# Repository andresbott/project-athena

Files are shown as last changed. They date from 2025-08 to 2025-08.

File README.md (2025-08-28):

# Project Athena
DIY PC Case Modding for Datahoarders 

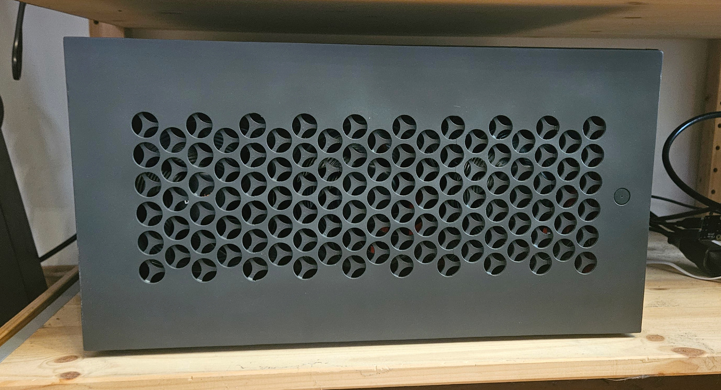
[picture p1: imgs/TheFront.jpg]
TheFront


## Background

When I was looking to replace my Home NAS, I desperately searched for an affordable, usable, and good-looking PC case with enough capacity for all my disks. Unfortunately, nowadays it is even hard to get a PC case that does not have a glass panel, and even harder to find one without a PSU shroud.

In the end, I settled on buying a *be quiet! Pure Base 500* and making the needed modifications myself: meet Project Athena.

## Features

With the modifications, you can set up a PC with **7×2.5" + 9×3.5" disks** or up to **25×2.5" disks** (depending on configuration) while keeping a regular ATX motherboard and PSU.

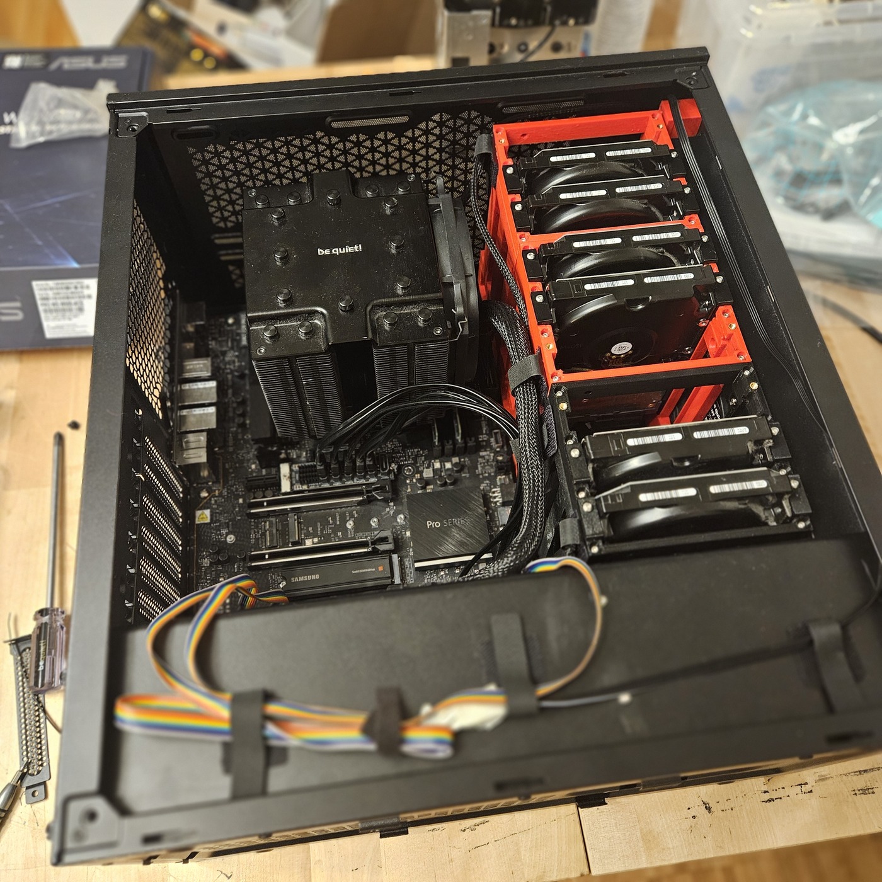
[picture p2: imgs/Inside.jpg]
Inside


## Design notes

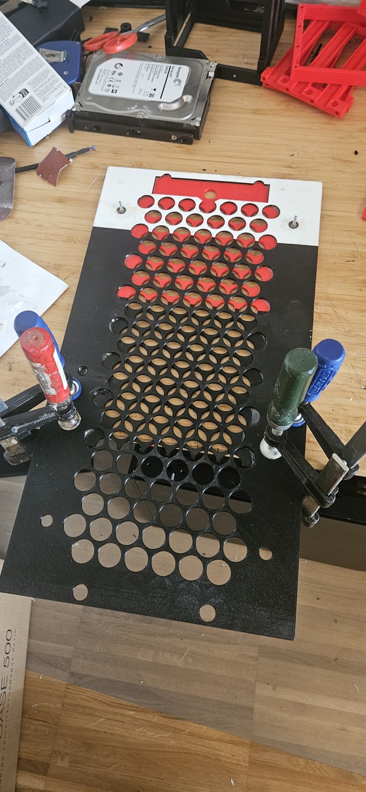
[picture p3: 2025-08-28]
imgs/TheFornt_01_Glue.jpg

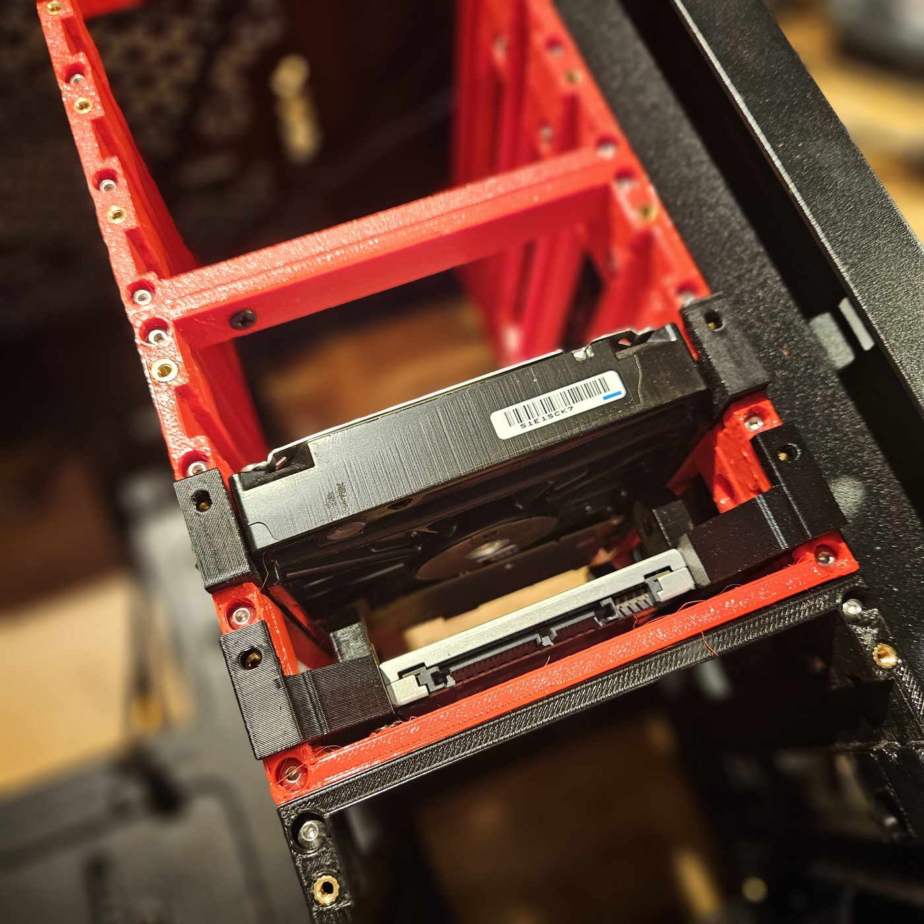
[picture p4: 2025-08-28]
imgs/DiskDetail.jpg

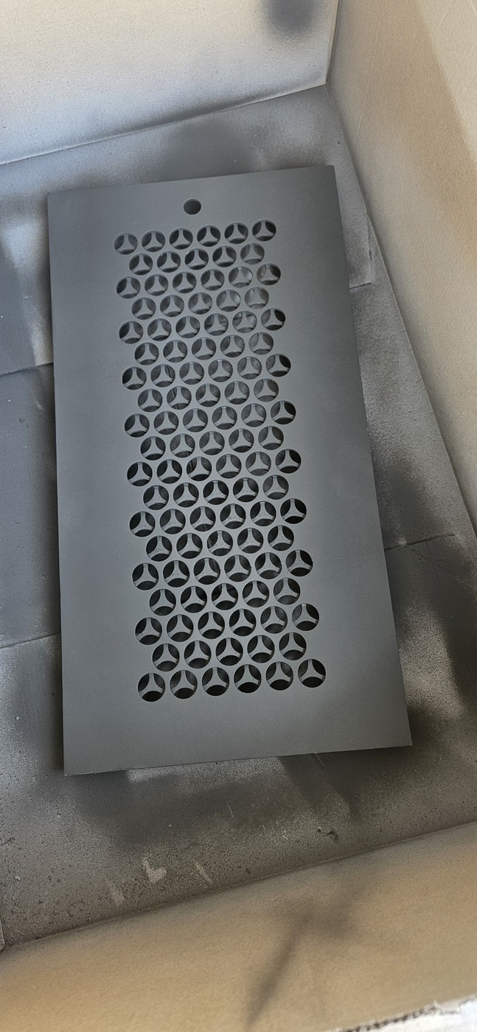
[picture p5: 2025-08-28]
imgs/TheFront_03_Paint.jpg

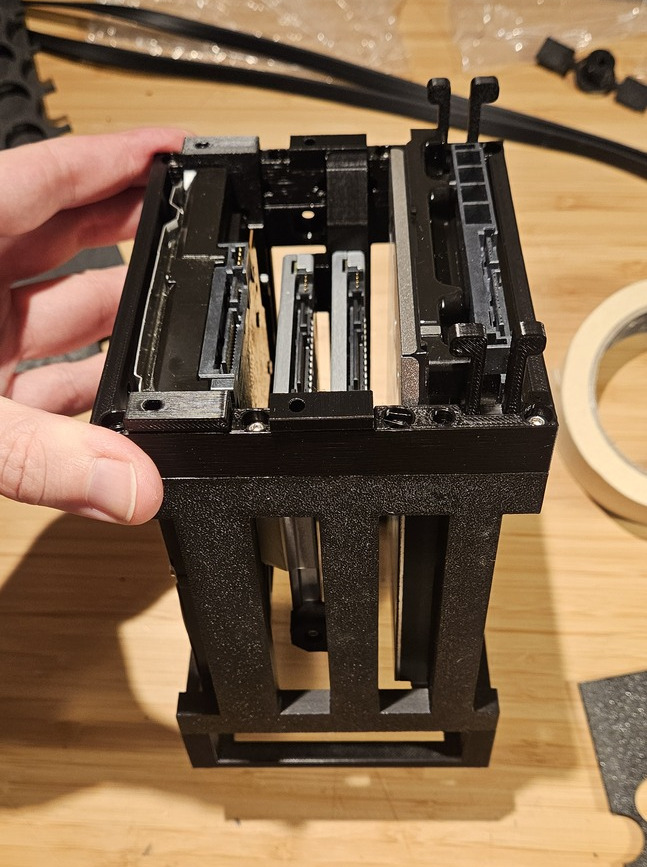
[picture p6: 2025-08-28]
imgs/HDD_Prototype_01.jpg

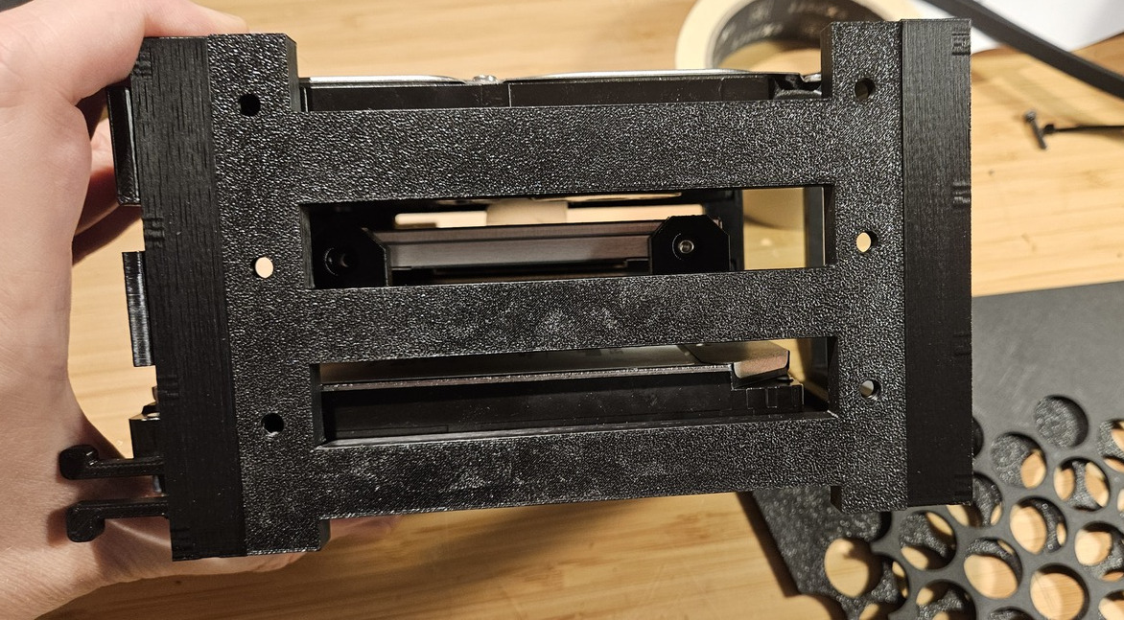
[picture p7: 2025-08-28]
imgs/HDD_Prototype_02.jpg

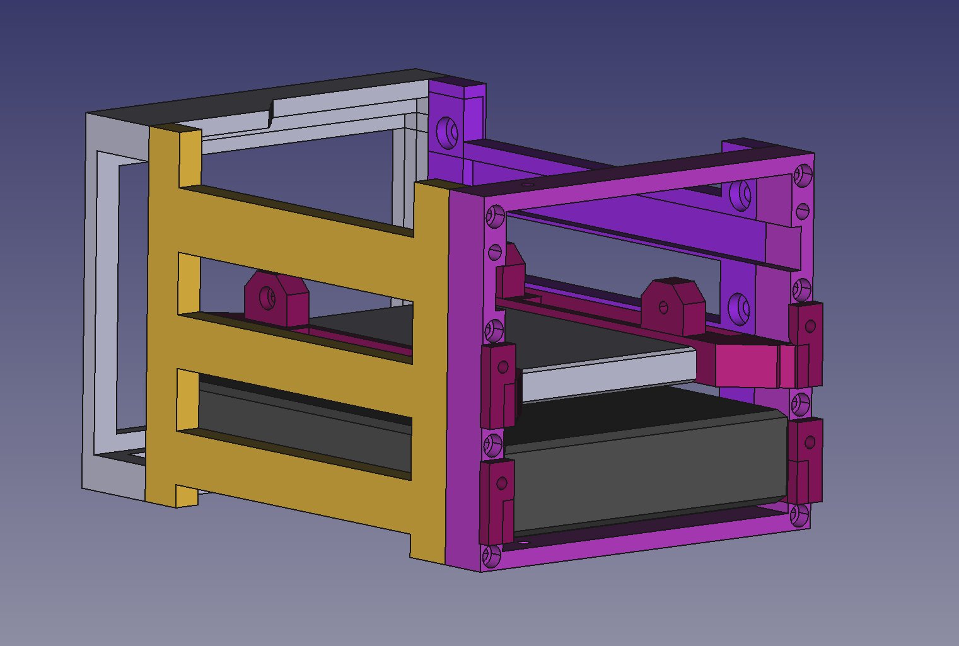
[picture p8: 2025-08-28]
HDDEnclosure/HDDEnclosure.jpg

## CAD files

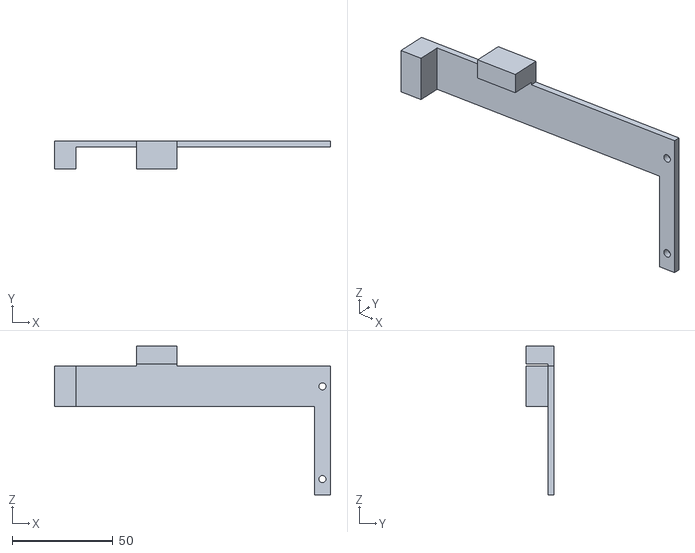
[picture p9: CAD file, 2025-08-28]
bottomSSD/files/SSDEnclosureBottom-HoleTemplate.obj
137.0 x 14.0 x 73.9

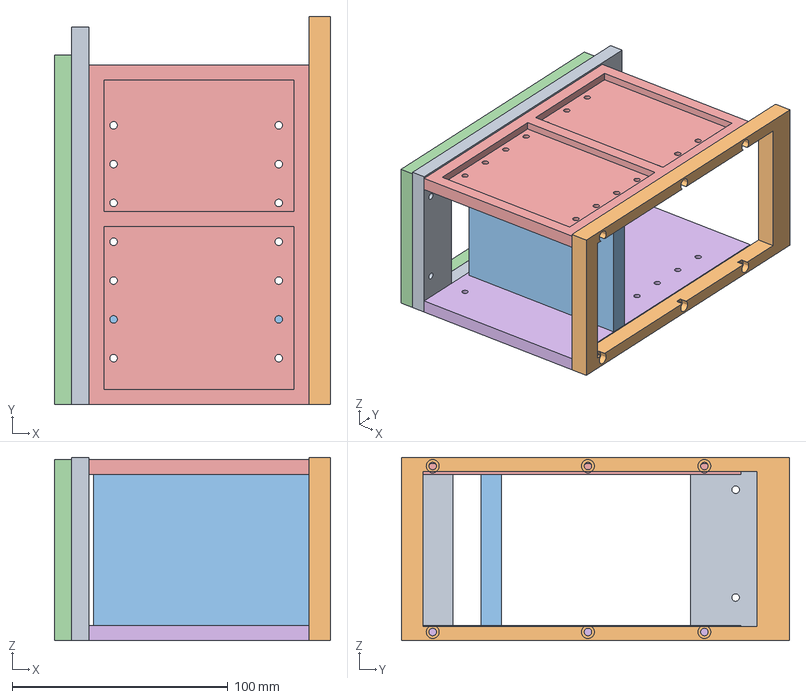
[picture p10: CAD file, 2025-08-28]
bottomSSD/SSDEnclosureBottom.FCStd
128.0 x 180.0 x 85.0 mm
Front
Back
SampleSSD
frontBracket
TopV2_2
bottomV2

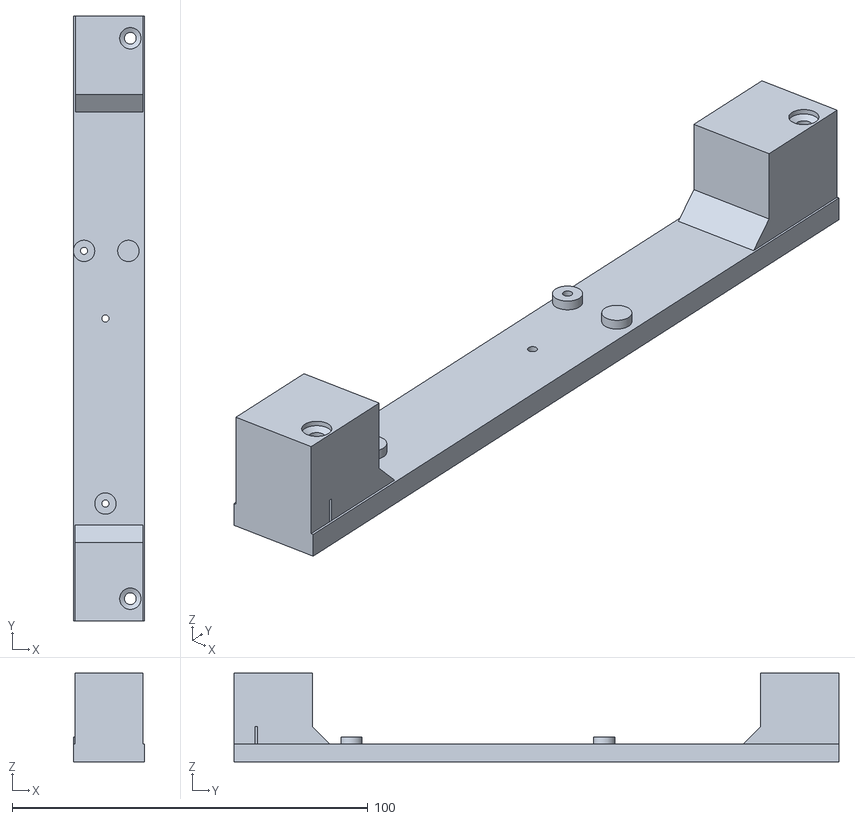
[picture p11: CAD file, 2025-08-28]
frontCover/files/frontCover-buttonPlate.obj
20.0 x 170.0 x 25.0

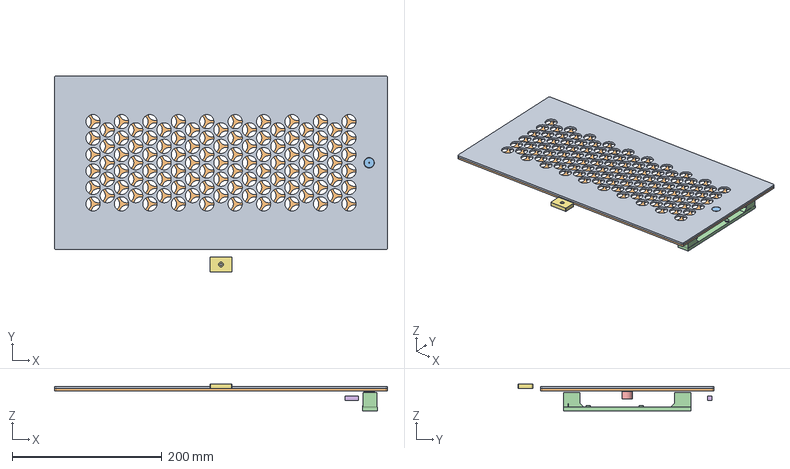
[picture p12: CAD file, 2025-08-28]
frontCover/frontCover.FCStd
445.0 x 262.0 x 36.0 mm
FrontPannel_Visible
FrontPannel_bottom
Button
buttonPlate
buttonp2
frontPlateHolder
pcFeet

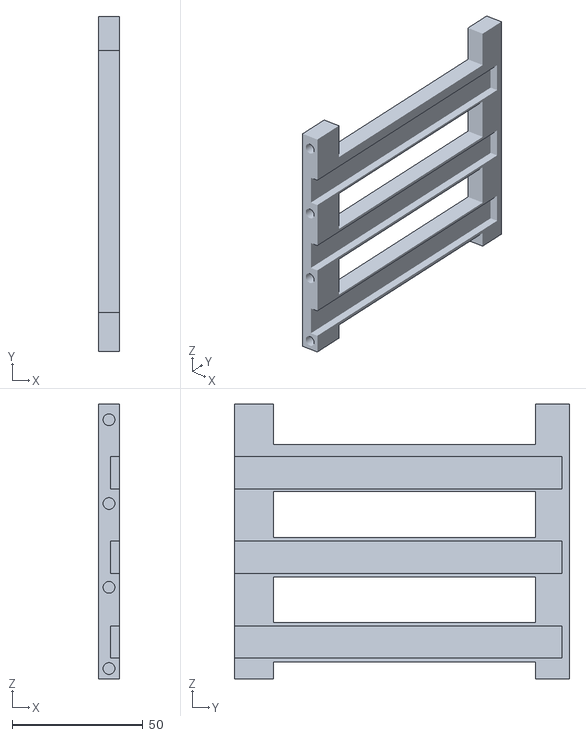
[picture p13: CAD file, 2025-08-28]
HDDEnclosure/files/HDDEnclosure-SideV2Short.obj
8.00 x 128.0 x 105.0

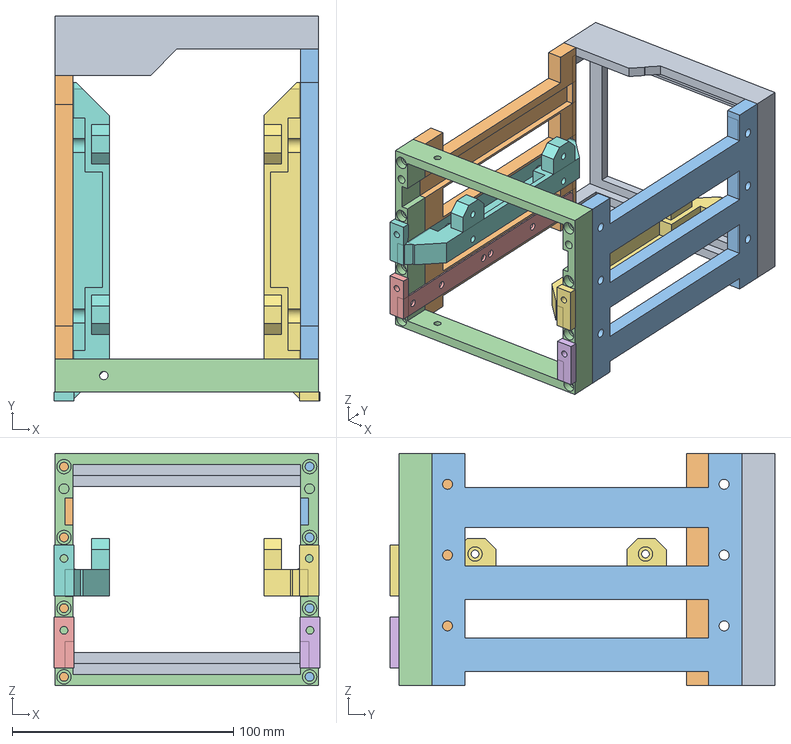
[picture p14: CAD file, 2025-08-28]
HDDEnclosure/HDDEnclosure.FCStd
120.2 x 174.0 x 105.0 mm
BackV2
SideV2Short
SideV2Long
FrontV2
hhdSideV2
hhdSideV2(mirrored)
ssdSideV2_SA001 (mirrored)
ssdSideV2_SA001

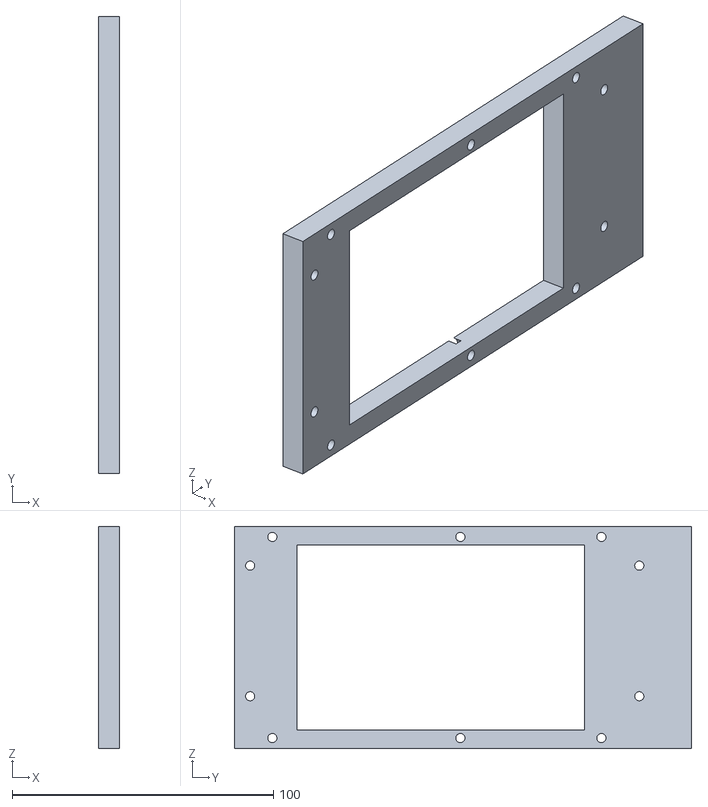
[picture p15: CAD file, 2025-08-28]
bottomSSD/files/SSDEnclosureBottom-Front.obj
8.00 x 175.0 x 85.0

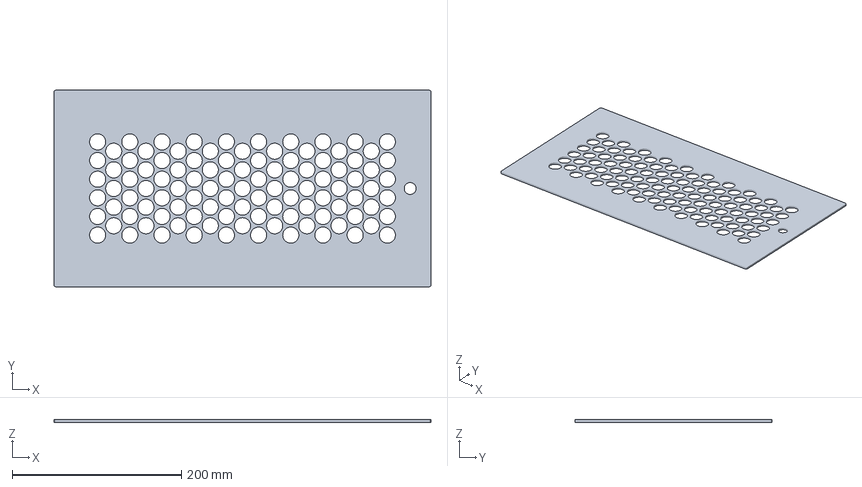
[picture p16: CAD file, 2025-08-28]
frontCover/files/frontCover-FrontPannel_Visible.amf
445.0 x 232.0 x 3.00 mm

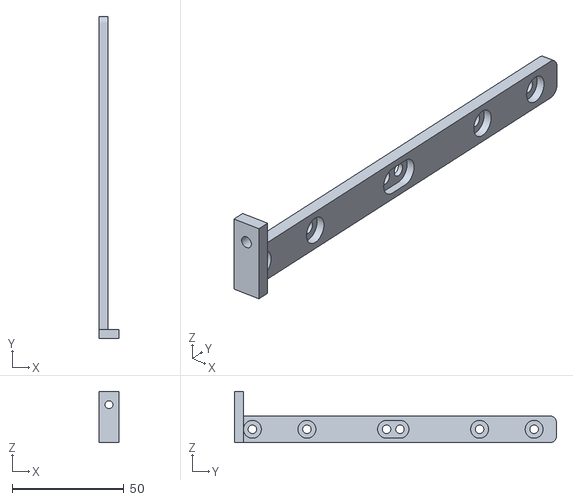
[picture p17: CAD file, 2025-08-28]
HDDEnclosure/files/HDDEnclosure-hhdSideV2(mirrored).obj
9.00 x 144.0 x 23.0

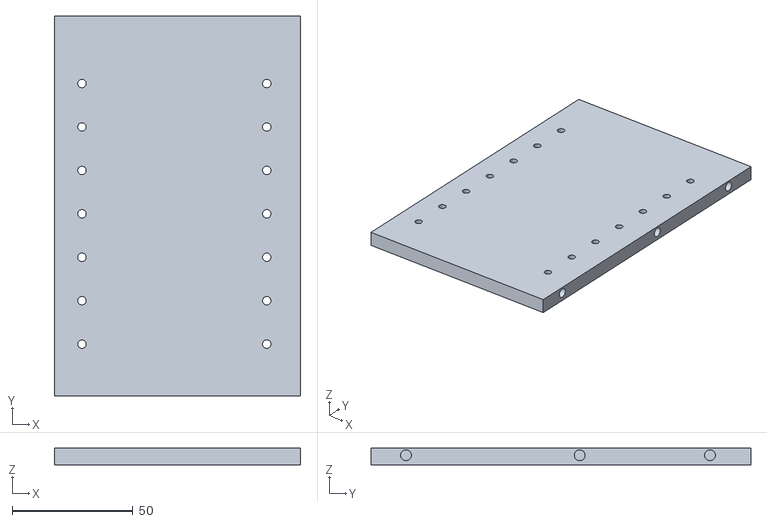
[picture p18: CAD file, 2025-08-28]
bottomSSD/files/SSDEnclosureBottom-bottomV2.obj
102.0 x 157.5 x 7.00

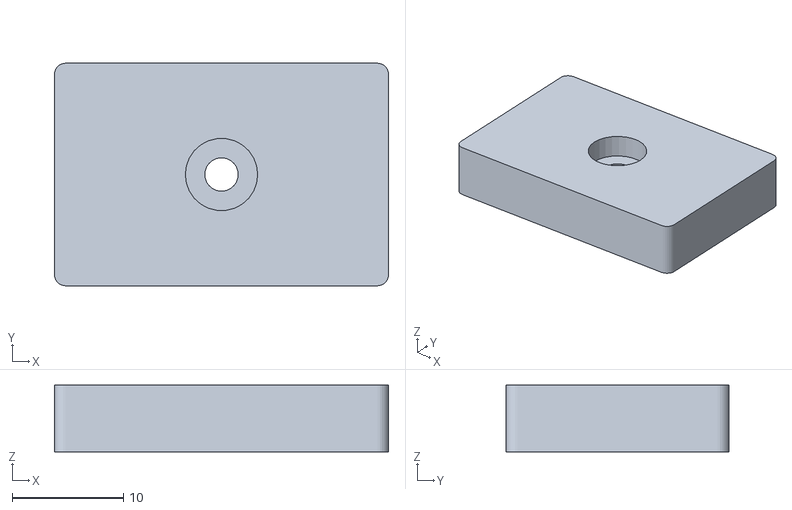
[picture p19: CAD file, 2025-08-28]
frontCover/files/frontCover-pcFeet.obj
30.0 x 20.0 x 6.00

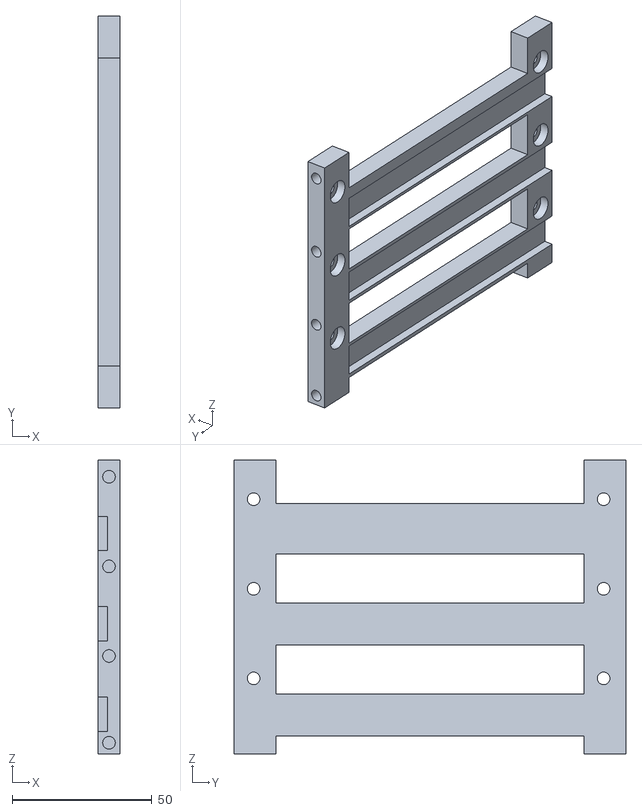
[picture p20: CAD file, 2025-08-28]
HDDEnclosure/files/HDDEnclosure-SideV2Long.obj
8.00 x 140.0 x 105.0

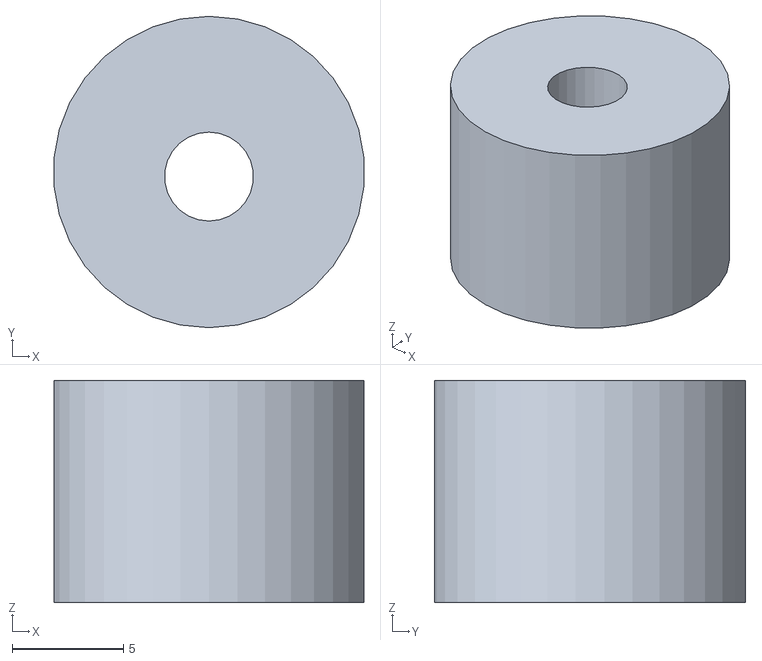
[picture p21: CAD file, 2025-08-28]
frontCover/files/frontCover-buttonp2.obj
13.9 x 14.0 x 10.0

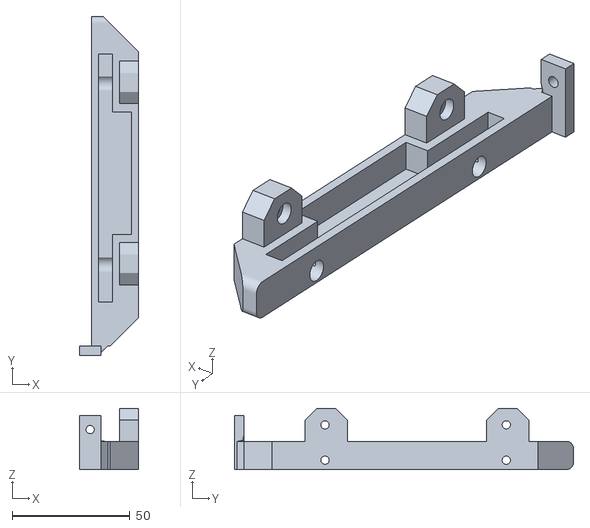
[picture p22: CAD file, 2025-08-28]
HDDEnclosure/files/HDDEnclosure-ssdSideV2_SA001.obj
25.0 x 144.0 x 26.0

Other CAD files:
bottomSSD/files/SSDEnclosureBottom-TopV2_2.obj
bottomSSD/files/SSDEnclosureBottom-Back.obj
frontCover/files/frontCover-FrontPannel_bottom.amf
HDDEnclosure/files/HDDEnclosure-FrontV2.obj
HDDEnclosure/files/HDDEnclosure-BackV2.amf
HDDEnclosure/files/HDDEnclosure-BackV2.obj
HDDEnclosure/files/HDDEnclosure-FrontV2.amf
HDDEnclosure/files/HDDEnclosure-SideV2Long.amf
HDDEnclosure/files/HDDEnclosure-SideV2Short.amf
HDDEnclosure/files/HDDEnclosure-hhdSideV2(mirrored).amf
HDDEnclosure/files/HDDEnclosure-hhdSideV2.amf
HDDEnclosure/files/HDDEnclosure-hhdSideV2.obj
HDDEnclosure/files/HDDEnclosure-ssdSideV2_SA001 (mirrored).amf
HDDEnclosure/files/HDDEnclosure-ssdSideV2_SA001 (mirrored).obj
HDDEnclosure/files/HDDEnclosure-ssdSideV2_SA001.amf
bottomSSD/files/SSDEnclosureBottom-Back.amf
bottomSSD/files/SSDEnclosureBottom-Front.amf
bottomSSD/files/SSDEnclosureBottom-HoleTemplate.amf
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

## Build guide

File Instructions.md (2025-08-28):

#  Instructions

## Materials

* be quiet be quiet base 500
* 3d Printed parts
* different size m3 screws
* m3 Brass threaded inserts 

#### Disclaimer

This is not a full fledged step by step instruction, but a bunch of notes that I took while mounting the PC.

If you decide to follow my steps, please contact me and we can improve this part.

## Mounting

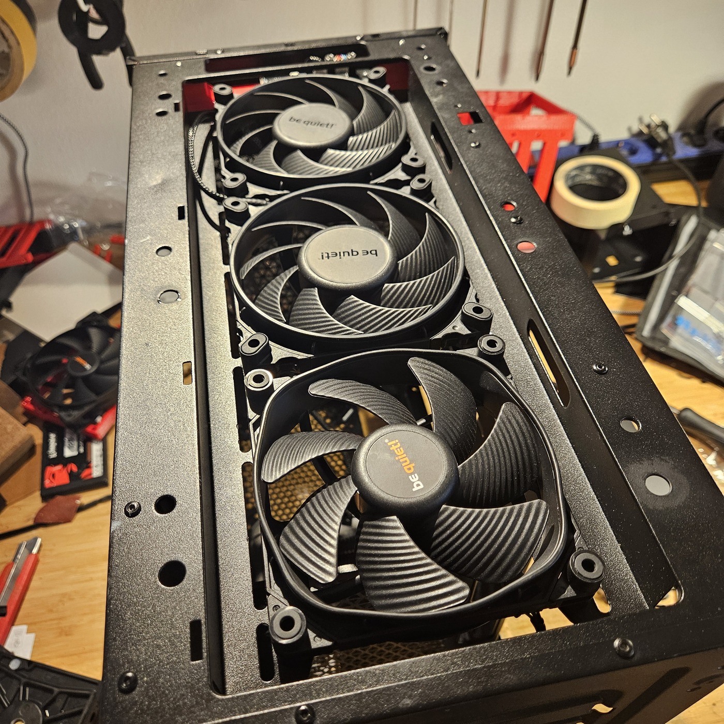
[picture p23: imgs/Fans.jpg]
Fans
1. Mount the 3x 12cm front fans, they need to be fixed from the inside with screws

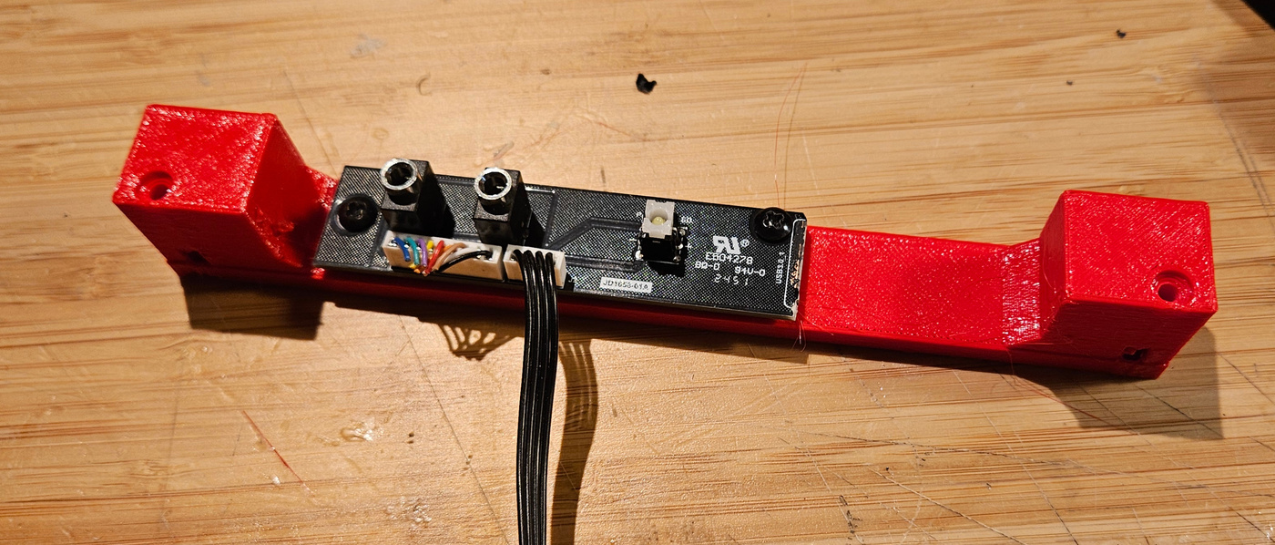
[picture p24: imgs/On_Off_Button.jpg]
On_Off_Button
2. Mount the on/off Button on top of the 3d printed part and then screw that in to the front. 

3. Mount the HHD enclosuers, using screws from the front side, using the 14cm rails, note that the bottom HDD enclosure i drilled a 4mm hole from the back surface (where the motherboard is screwed) and then fixed that there.

4. Mount the bottom side SSD holder, this is only the one piece that will be used later to fix the enclousre

5. Use the SSD hole template to drill 2x 4mm on the PSU shroud, used to fix the SSDs from the other side.

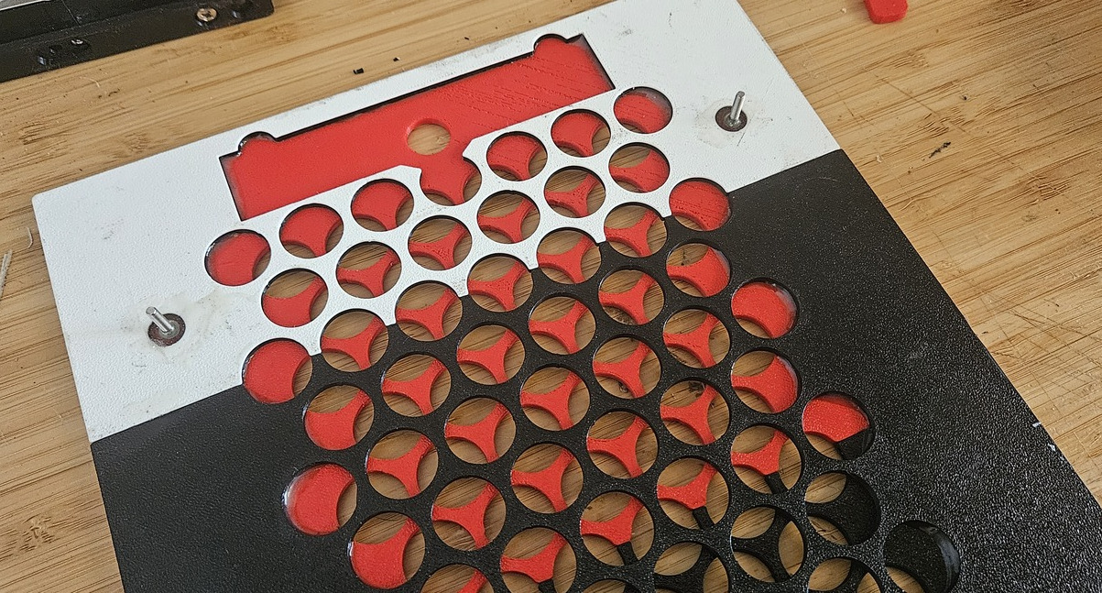
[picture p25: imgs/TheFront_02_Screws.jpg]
TheFront_02_Screws
6. Now using 6x the small 3d printed spacers, screw in the front panel; I used regular m3 nuts.

7. Pc mounting time: now You can put in the PSU, the SSDs in the bottom, cables

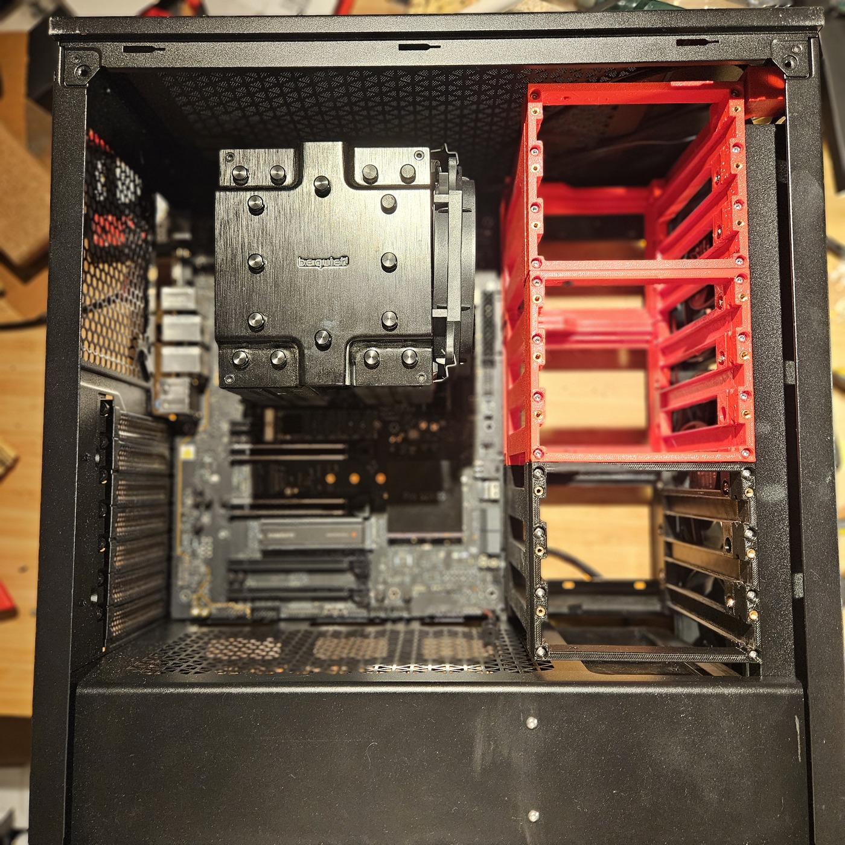
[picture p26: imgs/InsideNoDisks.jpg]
InsideNoDisks
   1. To mount the motherboard you will need to remove the 14cm extratc fan, otherwise probably it will note fit; Note that in my case it was quite tight to get the motherboard but it did fit in the end.
